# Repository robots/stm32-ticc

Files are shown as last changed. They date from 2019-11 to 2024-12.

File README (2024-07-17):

#STM32 based TICC

This project is based on TAPR's TICC project.

## Hardware

The frontend for time capture is copied from their schematic. Change has been done to input PICDIV that is responsible for coarse clock generation.

Original design uses pic12f675. For this design I have used pic12f1572. The software differences are only minor - few bank switch instructions. Hardware differense is almost none. Functional
difference is yet to be determined. But I dont think that the deterministic behavior of PIC has been changed.

Workhorse has been changed from ATMEGA to something more recent. I have used STM32F042.

This MCU has integrated 48MHz oscillator with clock recovery from USB, USB peripheral, lots of flash/ram for such simple project.

## Software

TICC presents on USB as ACM device. This works without any additional driver on linux. For windows i dont know - you will probably need ST's ACM driver. (google is your friend)

To connect use any terminal emulator you like - windows: realterm, teraterm, hyperterminal, ... for linux: minicom, screen, tio. Set speed to something reasonable (eg. 921600) and hit enter.

You should be presented with command line prompt ">".

Commands are:

help - prints help
reboot - reboots board
dfu - switches mcu to dfu mode. Carefull, you will need dfu-util to bring device back to live.
cfg - configuration submenu

cfg show - prints current configuration
cfg set xx blabla - sets variable "xx" to value "blabla"
cfg save - saves configuration to eeprom (not working yet)

Most configuration options are same as TICC, for more info refer to their documentation.

# Building
You will need gnuarm toolchain, gnu make and dfu-util.

Make sure that you have arm toolchain in PATH, enter "main" directory, and type "make bin".

To write the firmware to board use "dfu.sh" script. This script does two things: writes firmware and writes options to exit dfu mode.

# Credits
Software has been mostly written from scratch except for:
- usb stack, stdlibrary - from ST
- time interval calculation routines and TDC7200 driver  - from original TICC project, mostly rewritten or adapted for better readability - https://github.com/TAPR/TICC
- tfprintf - Copyright (C) 2004,2012  Kustaa Nyholm http://www.sparetimelabs.com/tinyprintf/index.html

Hardware:
- based on https://github.com/TAPR/TICC

# License
All files written by me are released to public domain. Use as you please. It would be nice to reference original repository if you do.

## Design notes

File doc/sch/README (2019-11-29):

In this directory:

ticc.* - schematic/board layout for TICC
picdiv.* - schematic/board layout for simple PICDIV board.

There is absolutely no warranty and not support for these boards. While there are few working examples of this design I dont have time or resources for support.

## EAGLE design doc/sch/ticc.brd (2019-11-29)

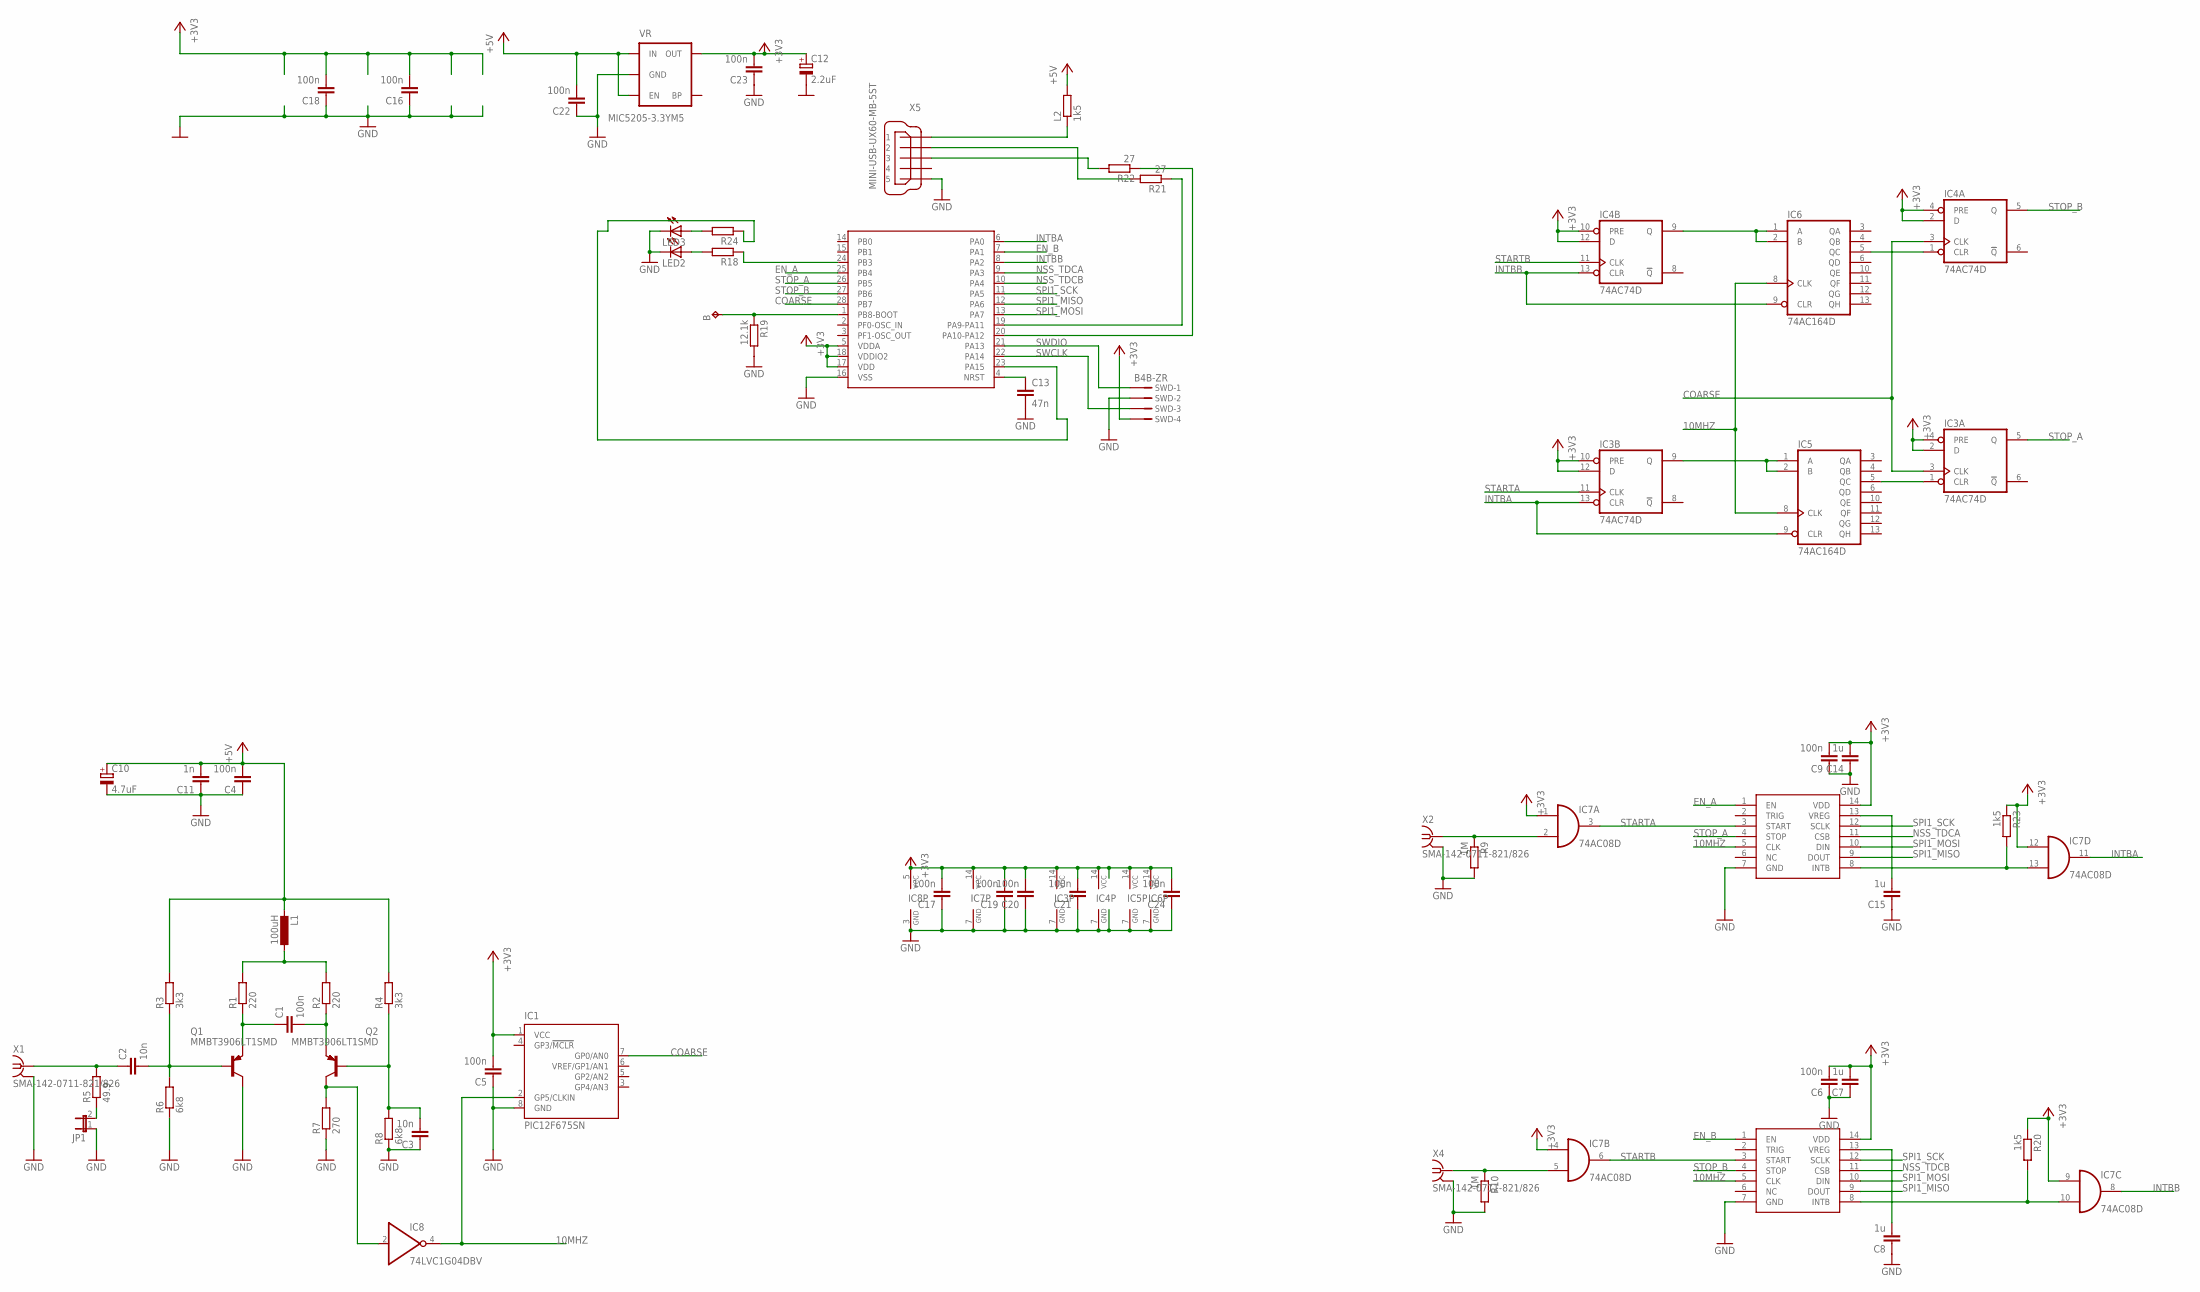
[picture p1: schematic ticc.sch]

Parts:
B: TPB1,27; B1,27
C1, C4, C5, C6, C9, C16, C17, C18, C19, C20, C21, C24: 100n; C0603
C2, C3: 10n; C0603
C7, C8, C14, C15: 1u; C0603
C10: 4.7uF; SMC_A
C11: 1n; C0603
C12: 2.2uF; SMC_A
C13: 47n; C0603
C22, C23: 100n; C0805K
IC1: PIC12F675SN; SO-08
IC3, IC4: 74AC74D; SO14
IC5, IC6: 74AC164D; SO14
IC7: 74AC08D; SO14
IC8: 74LVC1G04DBV; SOT23-5
JP1: JUMPER-2PTH; 1X02
L1: 100uH; L2012C
L2: 1k5; R0805
LED2, LED3: LEDCHIP-LED0805; CHIP-LED0805
Q1, Q2: MMBT3906LT1SMD; SOT23-BEC
R1, R2: 220; R0603
R3, R4: 3k3; R0603
R5: 49.9; R0603
R6, R8: 6k8; R0603
R7: 270; R0603
R9, R10: 1M; R0603
R18, R24: R-EU_R0603; R0603
R19: 12.1k; R0603
R20, R23: 1k5; R0603
R21, R22: 27; R0603
SWD: B4B-ZR
U$1: STM32F042G; QFN28
U$2, U$3: TDC7200; TSSOP14
VR: MIC5205-3.3YM5; SOT23-5
X1, X2, X4: SMA-142-0711-821/826; J502-ND-142-0711-821/826
X5: MINI-USB-UX60-MB-5ST; UX60-MB-5ST

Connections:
10MHZ: IC1.2 (GP5/CLKIN), IC5.8 (CLK), IC6.8 (CLK), IC8.4 (O), U$2.5 (CLK), U$3.5 (CLK)
+3V3: C5.2, C6.2, C7.2, C9.2, C12.+, C14.2, C16.2, C17.2, C18.2, C19.2, C20.2, C21.2, C23.2, C24.2, IC1.1 (VCC), IC3.2 (D), IC3.4 (PRE), IC3.10 (PRE), IC3.12 (D), IC3.14 (VCC), IC4.2 (D), IC4.4 (PRE), IC4.10 (PRE), IC4.12 (D), IC4.14 (VCC), IC5.14 (VCC), IC6.14 (VCC), IC7.1 (I0), IC7.4 (I0), IC7.9 (I0), IC7.12 (I0), IC7.14 (VCC), IC8.5 (VCC), R20.1, R23.1, SWD.4, U$1.5 (VDDA), U$1.17 (VDD), U$1.18 (VDDIO2), U$2.14 (VDD), U$3.14 (VDD), VR.5 (OUT)
+5V: C4.2, C10.+, C11.2, C22.2, L1.2, L2.2, R3.2, R4.2, VR.1 (IN), VR.3 (EN)
COARSE: IC1.7 (GP0/AN0), IC3.3 (CLK), IC4.3 (CLK), U$1.28 (PB7)
EN_A: U$1.25 (PB4), U$2.1 (EN)
EN_B: U$1.7 (PA1), U$3.1 (EN)
GND: C3.1, C4.1, C5.1, C6.1, C7.1, C8.1, C9.1, C10.-, C11.1, C12.-, C13.2, C14.1, C15.1, C16.1, C17.1, C18.1, C19.1, C20.1, C21.1, C22.1, C23.1, C24.1, IC1.8 (GND), IC3.7 (GND), IC4.7 (GND), IC5.7 (GND), IC6.7 (GND), IC7.7 (GND), IC8.3 (GND), JP1.1, LED2.C, LED3.C, Q1.C, R6.1, R7.1, R8.1, R9.2, R10.2, R19.2, SWD.2, U$1.16 (VSS), U$2.7 (GND), U$3.7 (GND), VR.2 (GND), X1.G@1 (GND), X1.G@2 (GND), X1.G@3 (GND), X1.G@4 (GND), X2.G@1 (GND), X2.G@2 (GND), X2.G@3 (GND), X2.G@4 (GND), X4.G@1 (GND), X4.G@2 (GND), X4.G@3 (GND), X4.G@4 (GND), X5.5
INTBA: IC3.13 (CLR), IC5.9 (CLR), IC7.11 (O), U$1.6 (PA0)
INTBB: IC4.13 (CLR), IC6.9 (CLR), IC7.8 (O), U$1.8 (PA2)
unnamed: C3.2, Q2.B, R4.1, R8.2
unnamed: JP1.2, R5.1
unnamed: C2.1, R5.2, X1.1
unnamed: C2.2, Q1.B, R3.1, R6.2
unnamed: L1.1, R1.2, R2.2
unnamed: C1.2, Q2.E, R2.1
unnamed: C1.1, Q1.E, R1.1
unnamed: R22.2, X5.3
unnamed: IC8.2 (I), Q2.C, R7.2
unnamed: IC7.2 (I1), R9.1, X2.1
unnamed: R21.2, X5.2
unnamed: IC7.5 (I1), R10.1, X4.1
unnamed: R18.1, U$1.24 (PB3)
unnamed: C15.2, U$2.13 (VREG)
unnamed: L2.1, X5.1
unnamed: R21.1, U$1.19 (PA9-PA11)
unnamed: IC3.1 (CLR), IC5.5 (QC)
unnamed: R22.1, U$1.20 (PA10-PA12)
unnamed: B.PP, R19.1, U$1.1 (PB8-BOOT)
unnamed: C13.1, U$1.4 (NRST)
unnamed: LED2.A, R18.2
unnamed: IC4.1 (CLR), IC6.5 (QC)
unnamed: IC3.9 (Q), IC5.1 (A), IC5.2 (B)
unnamed: IC4.9 (Q), IC6.1 (A), IC6.2 (B)
unnamed: R24.1, U$1.23 (PA15)
unnamed: IC7.10 (I1), R20.2, U$3.8 (INTB)
unnamed: IC7.13 (I1), R23.2, U$2.8 (INTB)
unnamed: LED3.A, R24.2
unnamed: C8.2, U$3.13 (VREG)
NSS_TDCA: U$1.9 (PA3), U$2.11 (CSB)
NSS_TDCB: U$1.10 (PA4), U$3.11 (CSB)
SPI1_MISO: U$1.12 (PA6), U$2.9 (DOUT), U$3.9 (DOUT)
SPI1_MOSI: U$1.13 (PA7), U$2.10 (DIN), U$3.10 (DIN)
SPI1_SCK: U$1.11 (PA5), U$2.12 (SCLK), U$3.12 (SCLK)
STARTA: IC3.11 (CLK), IC7.3 (O), U$2.3 (START)
STARTB: IC4.11 (CLK), IC7.6 (O), U$3.3 (START)
STOP_A: IC3.5 (Q), U$1.26 (PB5), U$2.4 (STOP)
STOP_B: IC4.5 (Q), U$1.27 (PB6), U$3.4 (STOP)
SWCLK: SWD.3, U$1.22 (PA14)
SWDIO: SWD.1, U$1.21 (PA13)

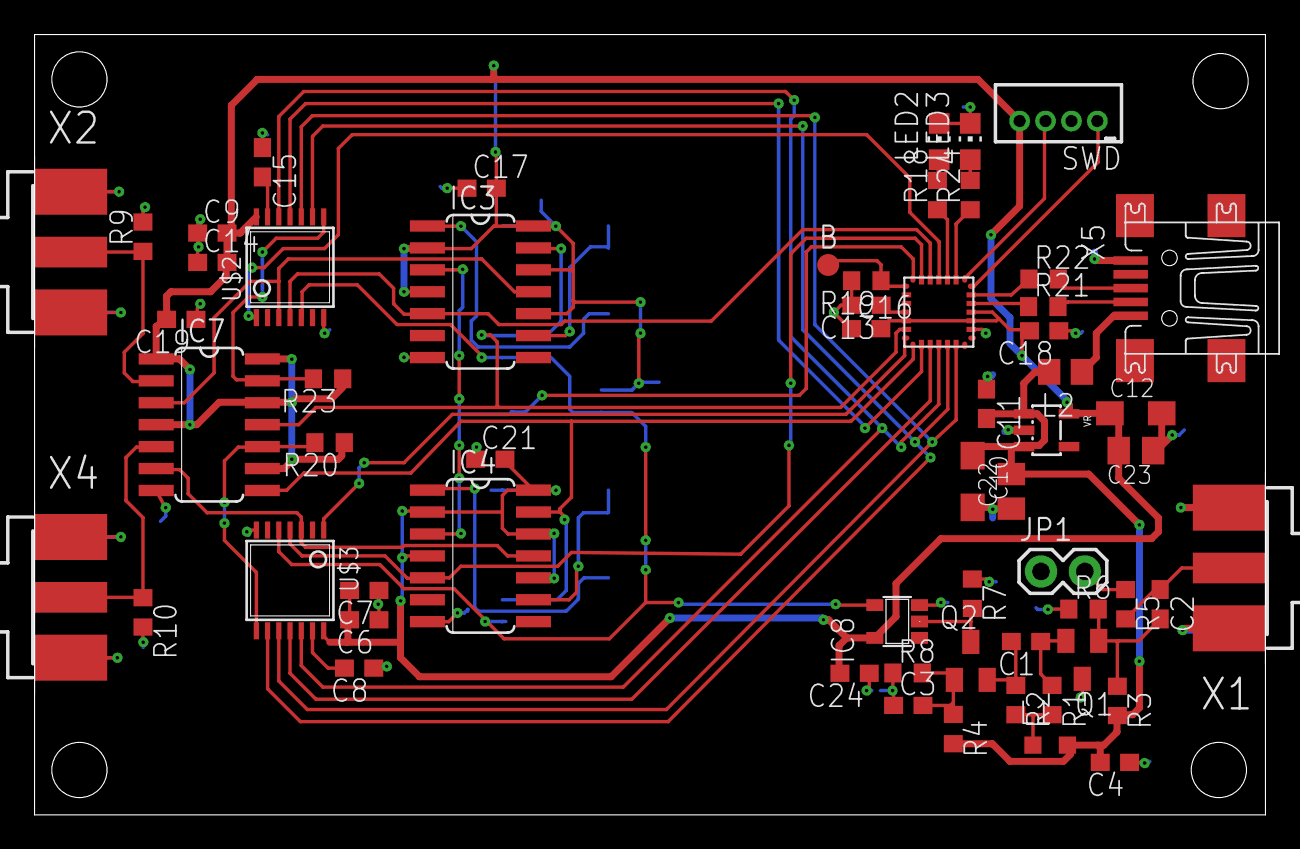
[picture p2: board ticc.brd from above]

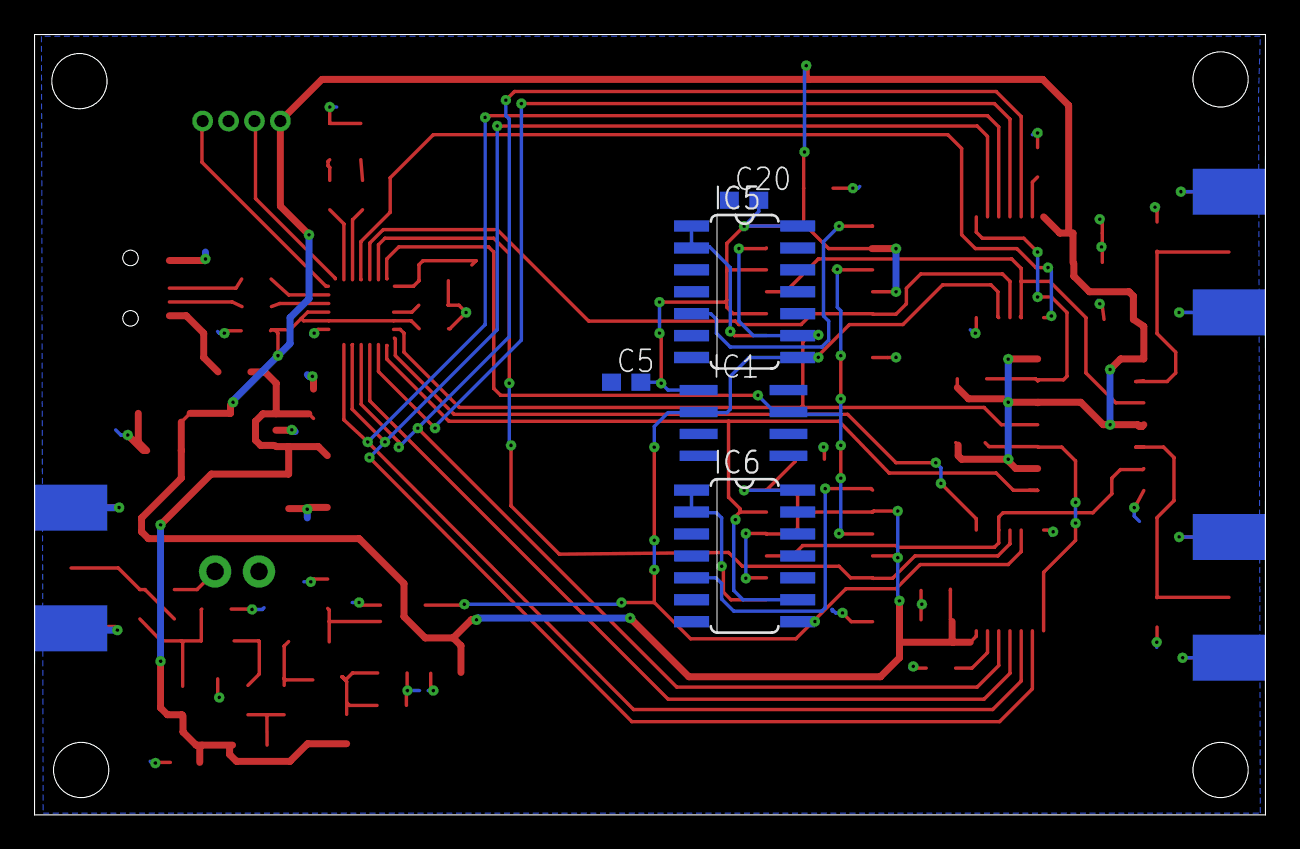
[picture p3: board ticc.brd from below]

Board: 2 copper layers, 71.3 x 45.2 mm, 65 parts (5 on the bottom side), 49 nets.

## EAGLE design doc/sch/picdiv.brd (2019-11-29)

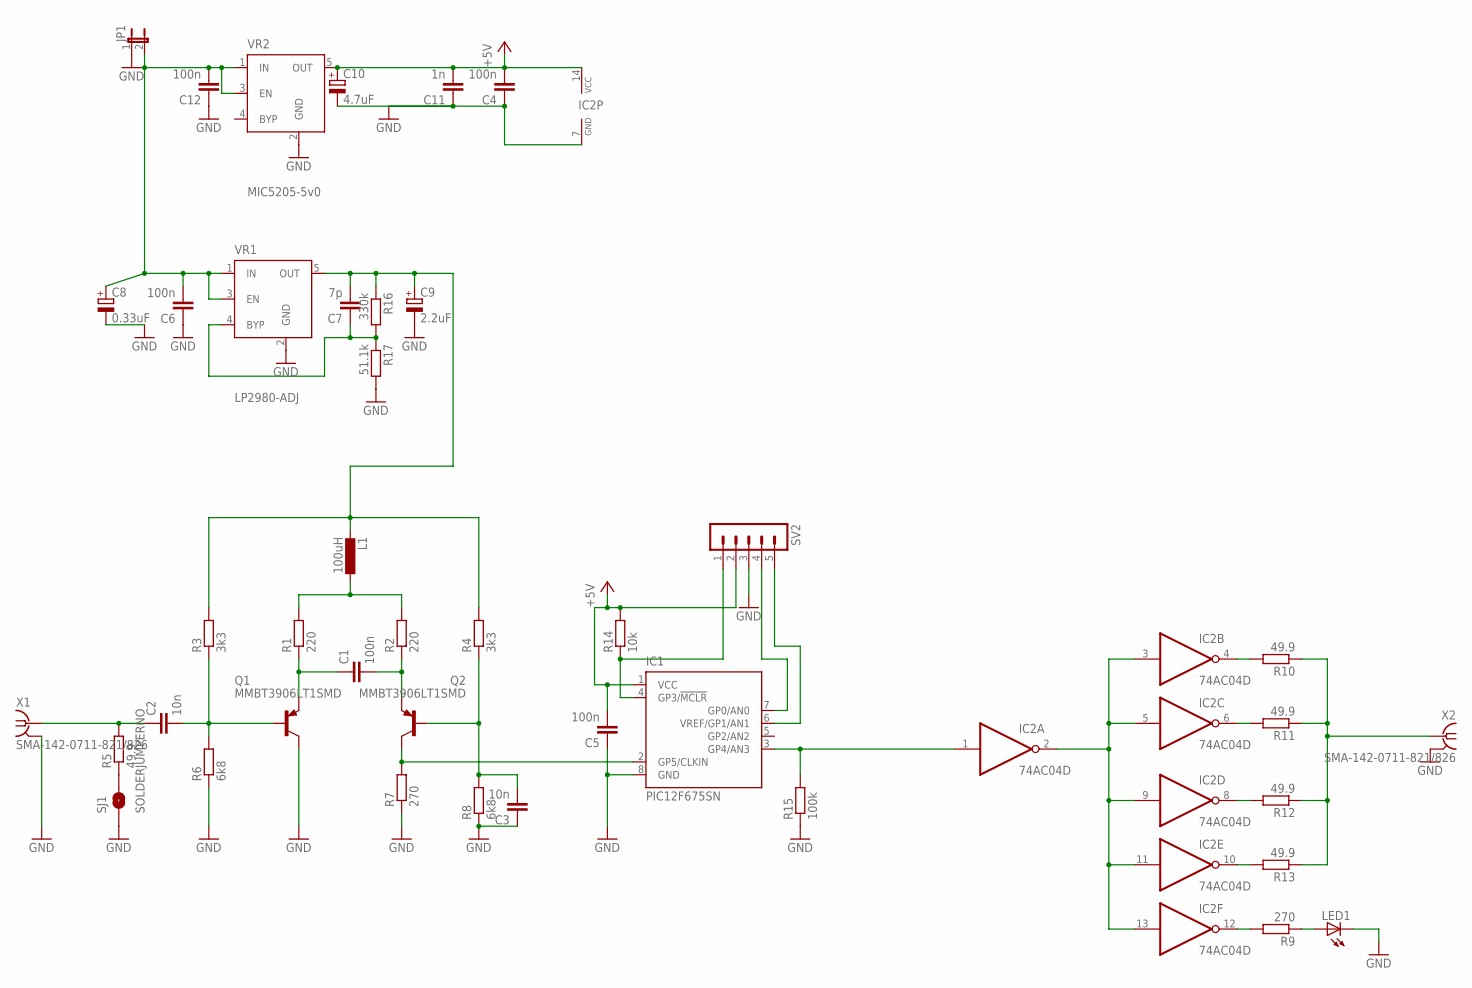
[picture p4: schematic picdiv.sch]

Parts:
C1, C4, C5, C6, C12: 100n; C0603
C2, C3: 10n; C0603
C7: 7p; C0603
C8: 0.33uF; SMC_A
C9: 2.2uF; SMC_A
C10: 4.7uF; SMC_A
C11: 1n; C0603
IC1: PIC12F675SN; SO-08
IC2: 74AC04D; SO14
JP1: JUMPER-2PTH; 1X02
L1: 100uH; L2012C
LED1: LEDCHIPLED_0603; CHIPLED_0603
Q1, Q2: MMBT3906LT1SMD; SOT23-BEC
R1, R2: 220; R0603
R3, R4: 3k3; R0603
R5, R10, R11, R12, R13: 49.9; R0603
R6, R8: 6k8; R0603
R7, R9: 270; R0603
R14: 10k; R0603
R15: 100k; R0603
R16: 330k; R0603
R17: 51.1k; R0603
SJ1: SOLDERJUMPERNO; SJ_2S-NO
SV2: MA05-1
VR1: LP2980-ADJ; SOT23-5
VR2: MIC5205-5v0; SOT23-5
X1, X2: SMA-142-0711-821/826; J502-ND-142-0711-821/826

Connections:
+5V: C4.2, C5.2, C10.+, C11.2, IC1.1 (VCC), IC2.14 (VCC), R14.2, SV2.2, VR2.5 (OUT)
+8V: C7.2, C9.+, L1.2, R3.2, R4.2, R16.1, VR1.5 (OUT)
GND: C3.1, C4.1, C5.1, C6.1, C8.-, C9.-, C10.-, C11.1, C12.1, IC1.8 (GND), IC2.7 (GND), JP1.1, LED1.C, Q1.C, R6.1, R7.1, R8.1, R15.1, R17.2, SJ1.1, SV2.3, VR1.2 (GND), VR2.2 (GND), X1.G@1 (GND), X1.G@2 (GND), X1.G@3 (GND), X1.G@4 (GND), X2.G@1 (GND), X2.G@2 (GND), X2.G@3 (GND), X2.G@4 (GND)
unnamed: C3.2, Q2.B, R4.1, R8.2
unnamed: R5.1, SJ1.2
unnamed: C2.1, R5.2, X1.1
unnamed: C2.2, Q1.B, R3.1, R6.2
unnamed: L1.1, R1.2, R2.2
unnamed: C1.2, Q2.E, R2.1
unnamed: C1.1, Q1.E, R1.1
unnamed: IC1.2 (GP5/CLKIN), Q2.C, R7.2
unnamed: IC2.12 (O), R9.2
unnamed: LED1.A, R9.1
unnamed: IC2.2 (O), IC2.3 (I), IC2.5 (I), IC2.9 (I), IC2.11 (I), IC2.13 (I)
unnamed: IC2.10 (O), R13.2
unnamed: IC2.4 (O), R10.2
unnamed: IC2.6 (O), R11.2
unnamed: IC2.8 (O), R12.2
unnamed: IC1.4 (GP3/!MCLR), R14.1, SV2.1
unnamed: C6.2, C8.+, C12.2, JP1.2, VR1.1 (IN), VR1.3 (EN), VR2.1 (IN), VR2.3 (EN)
unnamed: IC1.7 (GP0/AN0), SV2.4
unnamed: IC1.6 (VREF/GP1/AN1), SV2.5
OUT: R10.1, R11.1, R12.1, R13.1, X2.1
PICOUT: IC1.3 (GP4/AN3), IC2.1 (I), R15.2
VADJ: C7.1, R16.2, R17.1, VR1.4 (BYP)

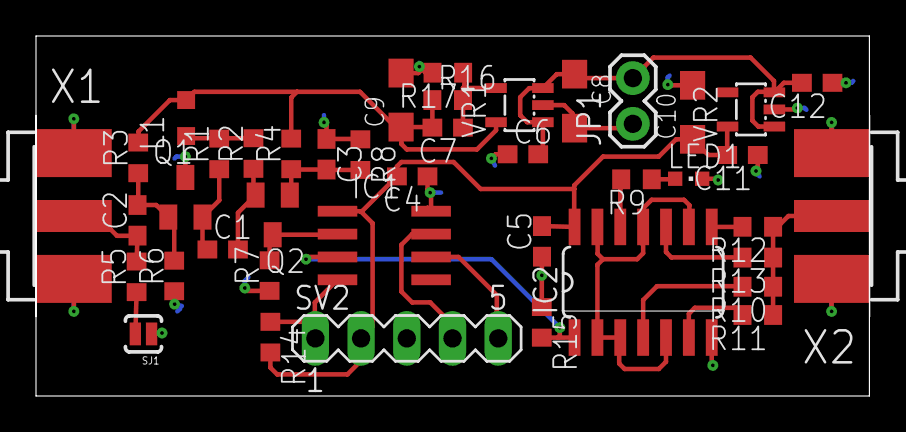
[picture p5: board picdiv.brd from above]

Board: 2 copper layers, 46.3 x 20.0 mm, 42 parts (0 on the bottom side), 25 nets.

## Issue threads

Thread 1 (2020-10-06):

picdiv source?

aewallin, 2020-10-06:
same comment as here: https://github.com/TAPR/TICC/issues/29

without the delay-functions include-file, how did you build the picdiv code??

robots, 2020-10-06:
these delay files are available from picdiv original source. I have added those files to the repository. I have used gpasm to assemble the binary.

robots, 2020-10-06:
http://www.leapsecond.com/pic/src/

Closed 2020-10-07.

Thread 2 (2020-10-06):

Throughput of 2-channel time-stamps?

aewallin, 2020-10-06:
Did you test how fast you can collect time-stamps from 2 channels?
This would be interesting if it can go fast, since noise averages down as 1/sqrt(N).
If it's possible to collect 10 000 time-stamps (on 2 channels) per second then the noise floor at tau=1s potentially goes from Xe-11 to Xe-13 at 1s, which is low enough for almost all microwave clocks (e.g. active hydrogen masers).

this could be tested with a signal-generator set to 1Hz, 10Hz, 100Hz, etc. and see when there are problems with throughput to the host computer.

robots, 2020-10-07:
i will test it when time permits. right now i dont have signal-generator at home and too busy at work

robots, 2024-12-21:
Sorry for very very late reply :) ... I have done some performance testing.  Though i have changed the ticc a bit:
- removed picdiv - coarse timer is now same as reference clock.
- coarse timer, stop a and stop b signals are routed to internal TIM3.
- outputs from IC5 and IC6 have been changed to Qa.

The result is: shorter period between end of pulse and stop signal, shorter recovery after pulse

With this setup I can go to about  500Hz reliably. At 1kHz or higher i get communication problems with the TDC chips.

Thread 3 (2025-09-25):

please provide a pdf schematic

7rx8, 2025-09-25:
hello

pdf schematics would be welcome to avoid requiring downloading your cad toolchain, thank you very much.

robots, 2025-09-25:
Here:
[ticc.pdf](https://github.com/user-attachments/files/22531678/ticc.pdf)

Schematic is in eagle, you can use also kicad to import the schematic/boards. No need to use _my_ toolchain :)

7rx8, 2025-09-25:
thank you, this is a great chip. not easy to get since it's only available at mouser and not a farnell, but I might build a board.

it looks easier to use, you just feed 10 MHz, and the chip just gives an interrupt when an input is triggered, then you just read the acquired timestamps in a fifo.

7rx8, 2025-10-03:
I have an AS6500 circuit almost ready. There are some quirks but it should work.

It seem that very few people have actually tried to use this awesome circuit to build TICC.

Closed 2025-09-25.

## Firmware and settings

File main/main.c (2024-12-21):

#include "platform.h"

#include "usbd_cdc_core.h"
#include "usbd_usr.h"

#include "console.h"
#include "systime.h"
#include "led.h"

#include "ticc.h"

USB_CORE_HANDLE	USB_Device_dev;

int main(void)
{
	SystemInit();
	RCC->AHBENR |= RCC_AHBPeriph_GPIOA | RCC_AHBPeriph_GPIOB;
	RCC->APB2ENR |= RCC_APB2Periph_SYSCFG;

	console_init();
	systime_init();
	led_init();
	ticc_init();

	USBD_Init(&USB_Device_dev, &USR_desc, &USBD_CDC_cb, &USR_cb);
	
	while (1) {
		systime_periodic();
		led_periodic();
		ticc_periodic();
	}
} 

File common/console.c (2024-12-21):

#include "platform.h"

#include <string.h>
#include <stdlib.h>
#include <stdio.h>
#include <stdarg.h>
#include <ctype.h>

#include "config.h"

// for dfu
#include "flash.h"
#include "usbd_cdc_core.h"

#include "printf.h"
//#include "console_uart.h"
#if CONSOLE_HAVE_TELNET
#include "console_telnet.h"
#endif
#if HAVE_SSL
#include "console_stelnet.h"
#endif
#if CONSOLE_HAVE_DMESG
#include "console_dmesg.h"
#endif
#if CONSOLE_HAVE_THREAD
#include "console_thread.h"
#endif
#include "console.h"

#undef DEBUG

static uint8_t cmd_help(struct console_session_t *cs, char **args);
static uint8_t cmd_verbose(struct console_session_t *cs, char **args);
static uint8_t cmd_reboot(struct console_session_t *cs, char **args);
static uint8_t cmd_dfu(struct console_session_t *cs, char **args);

static void console_auth_process(struct console_session_t *cs);
static void console_cmd_process(struct console_session_t *cs);

struct console_session_t console_sessions[CONSOLE_SESSION_NUM];

struct console_command_t console_command[] = {
	{ "help",    cmd_help,  "Prints help", "Help:\n command - prints help about command", NULL },
	{ "verbose", cmd_verbose, "Verbosity", "Verbosity\n x - Set verbosity level for this terminal", NULL },
	{ "reboot",  cmd_reboot, "Reboot immediately", "Reboot:\n boot - reboots into bootloader", NULL },
	{ "dfu",     cmd_dfu,    "Enter mcu's DFU mode", "", NULL },
};

const char console_crlf[] = "\r\n";
const char console_bs[] = "\x08 \x08";

const char *console_prompts[] = {
	"User:",
	"Pass:",
	">",
};

void console_init(void)
{
	uint32_t i;

	struct console_command_t *cmd = &console_command[0];
	for (i = 1; i < ARRAY_SIZE(console_command); i++) {
		cmd->next = &console_command[i];
		if (cmd->cmd == NULL)
			continue;
		cmd = cmd->next;
	}

	for (i = 0; i < CONSOLE_SESSION_NUM; i++) {
		memset(&console_sessions[i], 0, sizeof(struct console_session_t));
	}

#if CONSOLE_HAVE_DMESG
	console_dmesg_init();
#endif
	//console_uart_init();
#if CONSOLE_HAVE_THREAD
	console_thread_init();
#endif
}

void console_periodic(void)
{
#if CONSOLE_HAVE_THREAD
	uint32_t i;

	for (i = 0; i < CONSOLE_SESSION_NUM; i++) {
		if (console_sessions[i].used) {
			console_thread_handle(&console_sessions[i]);
		}
	}
#endif
}

void console_add_command(struct console_command_t *new_cmd)
{
	struct console_command_t *cmd = &console_command[0];

	if (new_cmd->next) {
		return;
	}

	while (cmd->next != NULL) {
		cmd = cmd->next;
	}

	cmd->next = new_cmd;
}

void console_lock(void)
{
	//console_uart_disable_int();
}

void console_unlock(void)
{
	//console_uart_enable_int();
}

void cprintf(char *fmt, ...)
{
	char out[CONSOLE_CMD_OUTBUF];
	uint32_t len;

	va_list va;
	va_start(va, fmt);
	len = tfp_vsprintf(out, fmt, va);
	va_end(va);

	console_write(CON_ERR, out, len);
}

void console_print_hex(uint8_t level, const char *buf, uint32_t buf_len)
{
	char out[CONSOLE_CMD_OUTBUF];
	uint32_t len = 0;
	uint32_t i;

	for (i = 0; i < buf_len; i++) {
		len += tfp_sprintf(out+len, "%02x ", buf[i]);
	}

	console_printf(level, "%s\n", out);
}

void console_printf(uint8_t level, const char *fmt, ...)
{
	char out[CONSOLE_CMD_OUTBUF];
	uint32_t len;

	va_list va;
	va_start(va, fmt);
	len = tfp_vsprintf(out, fmt, va);
	va_end(va);

	console_write(level, out, len);
}

static void console_output(uint8_t level, const char *buf, uint32_t len)
{
	uint32_t i;

	for (i = 0; i < CONSOLE_SESSION_NUM; i++) {
		if (console_sessions[i].used) {
			if (console_sessions[i].auth_state == CON_AUTH_OK) {
				if (console_sessions[i].verbosity >= level) {
					console_sessions[i].output(&console_sessions[i], buf, len);
				}
			}
		}
	}
}

static void console_output_prompt(uint8_t level)
{
	uint32_t i;

	for (i = 0; i < CONSOLE_SESSION_NUM; i++) {
		if (console_sessions[i].used) {
			if (console_sessions[i].auth_state == CON_AUTH_OK) {
				if (console_sessions[i].verbosity >= level) {
					if (console_sessions[i].cmd_len) {
						console_print_prompt(&console_sessions[i]);

						console_sessions[i].output(&console_sessions[i], console_sessions[i].cmd_buf, console_sessions[i].cmd_len);
					}
				}
			}
		}
	}
}

static void console_output_cr(uint8_t level)
{
	uint32_t i;

	for (i = 0; i < CONSOLE_SESSION_NUM; i++) {
		if (console_sessions[i].used) {
			if (console_sessions[i].auth_state == CON_AUTH_OK) {
				if (console_sessions[i].verbosity >= level) {
					if (console_sessions[i].cmd_len > 0) {
						console_sessions[i].output(&console_sessions[i], "\r", 1);
					}
				}
			}
		}
	}
}
void console_write(uint8_t level, const char *buf, uint32_t len)
{
	uint32_t l = len;
	const char *start = buf;
	const char *end;

	console_output_cr(level);

	// rewrite all \n to \r\n
	while (l && ((end = strchr(start, '\n')) != NULL)) {
		uint32_t w = end-start;

		if (w > l) {
			w = l;
		}

		console_output(level, start, w);
		console_output(level, console_crlf, sizeof(console_crlf));

#if CONSOLE_HAVE_DMESG
		console_dmesg_putbuf(start, w);
		console_dmesg_putbuf(console_crlf, sizeof(console_crlf));
#endif

		l -= w+1;
		start = end+1;
	}

	if (l) {
		console_output(level, start, l);
#if CONSOLE_HAVE_DMESG
		console_dmesg_putbuf(start, l);
#endif
	}

	// finish writing to console by showing prompt
	console_output_prompt(level);
}

void console_session_output(struct console_session_t * cs, const char *buf, uint32_t len)
{
	uint32_t l = len;
	const char *start = buf;
	const char *end;

	// rewrite all \n to \r\n
	while (l && ((end = strchr(start, '\n')) != NULL)) {
		uint32_t w = end-start;

		if (w > l) {
			w = l;
		}

		cs->output(cs, start, w);
		cs->output(cs, console_crlf, sizeof(console_crlf));


		l -= w+1;
		start = end+1;
	}

	if (l) {
		cs->output(cs, start, l);
	}
}

void console_session_printf(struct console_session_t *cs, const char *fmt, ...)
{
	char out[CONSOLE_CMD_OUTBUF];
	uint32_t len;

	va_list va;
	va_start(va, fmt);
	len = tfp_vsprintf(out, fmt, va);
	va_end(va);

	console_session_output(cs, out, len);
}

uint8_t console_session_init(struct console_session_t **cs, session_output_t output, session_close_t close)
{
	uint32_t i;

	for (i = 0; i < CONSOLE_SESSION_NUM; i++) {
		if (console_sessions[i].used == 0) {
			break;
		}
	}

	if (i >= CONSOLE_SESSION_NUM) {
		return 1;
	}

	memset(&console_sessions[i], 0, sizeof(struct console_session_t));
	console_sessions[i].used = 1;
	console_sessions[i].output = output;
	console_sessions[i].close = close;
	console_sessions[i].verbosity = CON_ERR;

	*cs = &console_sessions[i];

	return 0;
}

void console_session_close(struct console_session_t *cs)
{
	cs->used = 0;
	cs->auth_state = 0;
	cs->flags = 0;
	cs->output = NULL;
}

void console_print_prompt(struct console_session_t *cs)
{
	const char *p;

	p = console_prompts[cs->auth_state];
	cs->output(cs, p, strlen(p));
}
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

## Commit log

2019-11-29 Initial commit of public version
    [picdiv.brd, picdiv.sch, ticc.brd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]
2024-12-21 update gpio driver
2024-12-21 main: add missing include
    [main.c]

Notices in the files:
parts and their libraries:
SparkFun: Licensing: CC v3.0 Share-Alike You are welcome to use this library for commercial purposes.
